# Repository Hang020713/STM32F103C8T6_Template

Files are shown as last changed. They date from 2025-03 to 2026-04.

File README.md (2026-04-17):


# About This Project

A custom STM32F103C8T6 PCB template designed for hand-soldering, prototyping, and embedded system development.
This board serves as a solid starting point for STM32-based projects, robotics systems, and embedded applications.

---

# 📟 Board Preview

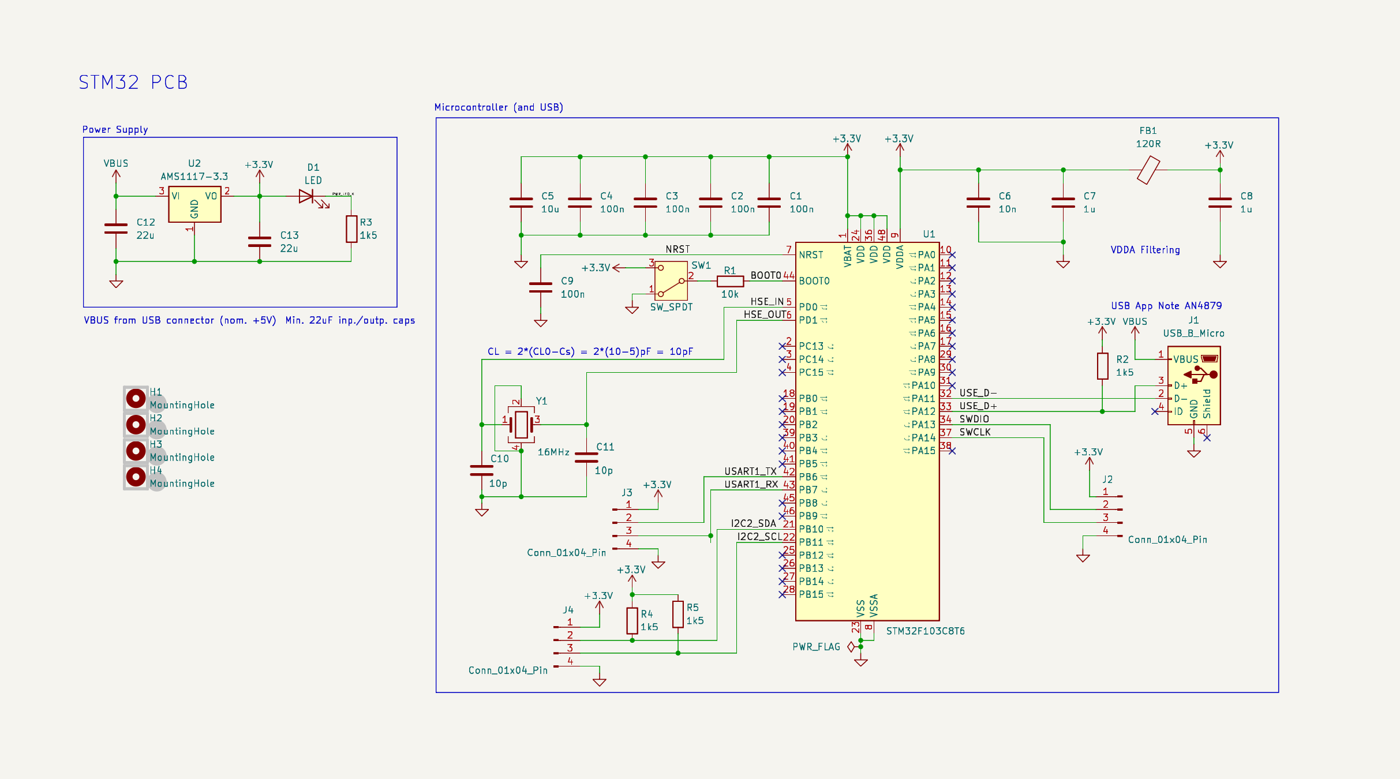
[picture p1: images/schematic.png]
schematic

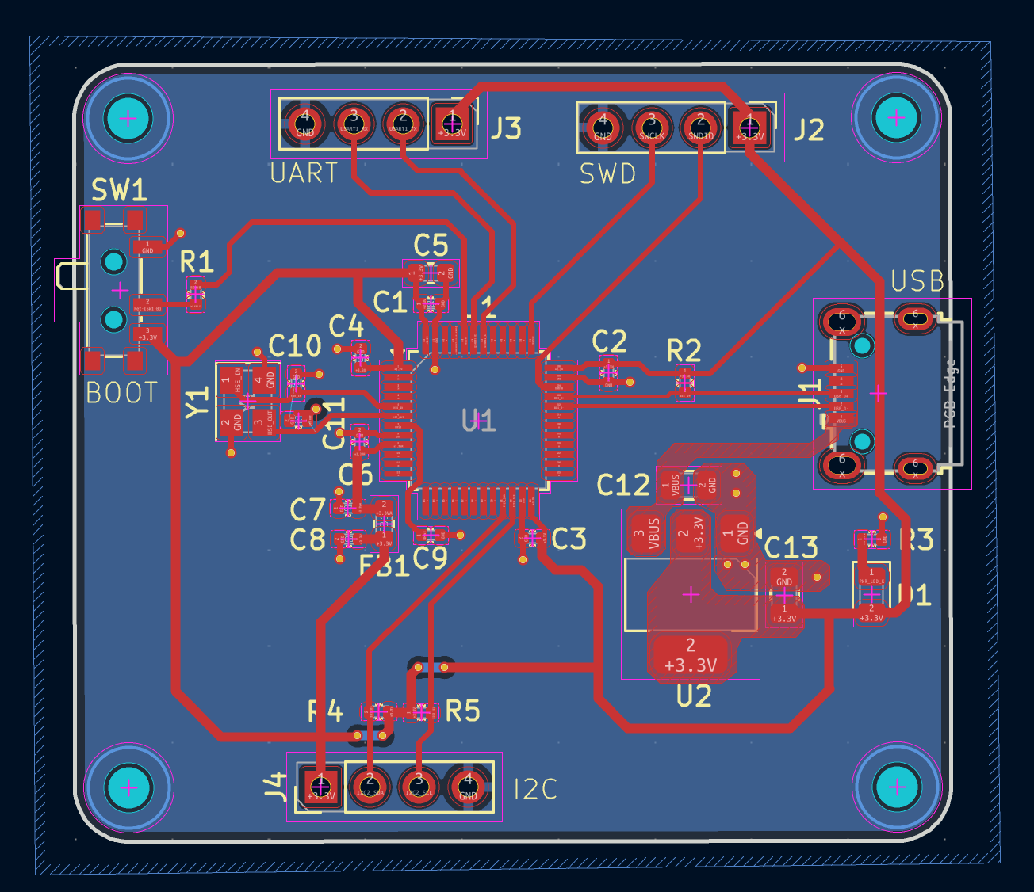
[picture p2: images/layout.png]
layout

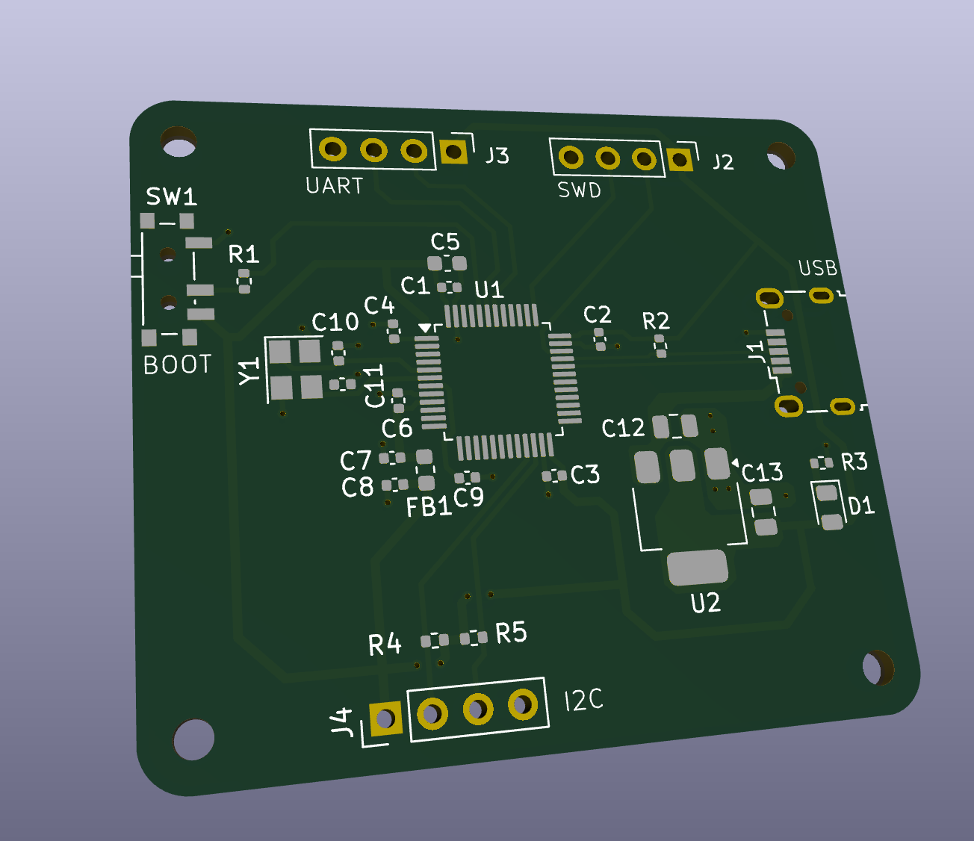
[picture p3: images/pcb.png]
[pcb]


---

# 📁 File Structure

<!-- TREEVIEW START -->
```bash
├── stm32f103c8t6.kicad_pcb   # PCB Layout
├── stm32f103c8t6.kicad_pro   # KiCad Project File
├── stm32f103c8t6.kicad_sch   # Schematic
└── README.md
```

## File Descriptions
* `kicad_pcb` - PCB Layout
* `kicad_sch` - Schematic
* `kicad_pro` - KiCad Project Configuration File
<!-- TREEVIEW END -->

---

# 🚀 Getting Started

Requirements
* KiCad 8 (recommended)

Open the `.kicad_pro` file using KiCad 8 to access the full project including schematic and PCB layout.

---

# 🔧 Board Feature

STM32 Board have below features
- [x] Hand-solder friendly footprint design
- [x] 5V Voltage Regulator
- [x] Micro USB Connector
- [x] 1 x UART Interface
- [x] 1 x I2C Interface
- [x] BOOT Button
- [x] SWD Debugging Interface
- [x] 16 MHz External Crystal Oscillator
- [ ] USB-C Connector

---

# 🧠 Usage

STM32 have a deep potential. You could modify this board to extend more pins you want. Example:

* Expose additional GPIO Pins
* Add SPI peripherals
* Integreate sensors (IMU, barometer, etc.)
* Add motor drivers

---

# License

MIT License

Feel free to use, modify, and distribute.

---

## 📫 Let's Connect

I'm always interested in collaborating on embedded systems projects, robotics competitions, or autonomous vehicle development!







---

<p align="right">(<a href="#readme-top">Back to Top</a>)</p>

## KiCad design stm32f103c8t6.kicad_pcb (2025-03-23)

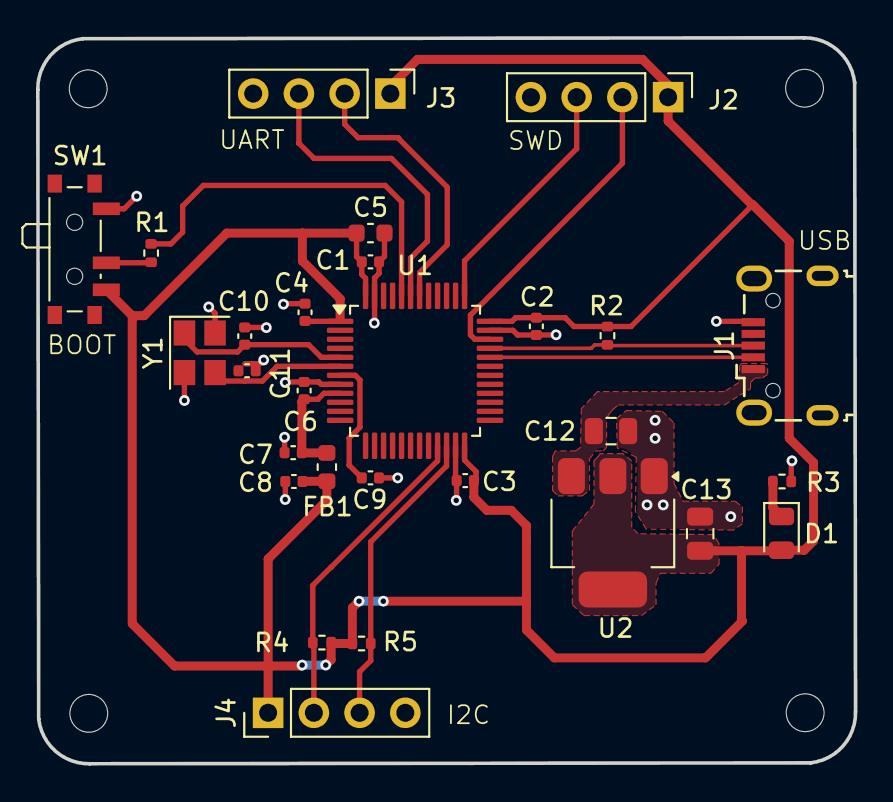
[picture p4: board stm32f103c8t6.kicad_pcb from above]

Board: 2 copper layers, 45.4 x 40.3 mm, 32 parts (0 on the bottom side), 18 nets.

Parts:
C1, C2, C3, C4, C9: 100n; C_0402_1005Metric
C5: 10u; C_0603_1608Metric
C6: 10n; C_0402_1005Metric
C7, C8: 1u; C_0402_1005Metric
C10, C11: 10p; C_0402_1005Metric
C12, C13: 22u; C_0805_2012Metric
D1: LED; LED_0805_2012Metric
FB1: 120R; L_0603_1608Metric
H1, H2, H3, H4: MountingHole; MountingHole_2.1mm
J1: USB_B_Micro; USB_Micro-B_Wuerth_629105150521
J2, J3, J4: Conn_01x04_Pin; PinHeader_1x04_P2.54mm_Vertical
R1: 10k; R_0402_1005Metric
R2, R3, R4, R5: 1k5; R_0402_1005Metric
SW1: SW_SPDT; SW_SPDT_PCM12
U1: STM32F103C8T6; LQFP-48_7x7mm_P0.5mm
U2: AMS1117-3.3; SOT-223-3_TabPin2
Y1: 16MHz; Crystal_SMD_3225-4Pin_3.2x2.5mm

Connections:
+3.3V: C1.1, C2.1, C3.1, C4.1, C5.1, C8.1, C13.1, D1.2 (A), FB1.1, J2.1, J3.1, J4.1, R2.1, R4.1, R5.1, SW1.3 (C), U1.1 (VBAT), U1.24 (VDD), U1.36 (VDD), U1.48 (VDD), U2.2 (VO)
+3.3VA: C6.1, C7.1, FB1.2, U1.9 (VDDA)
/BOOT0: R1.2, U1.44 (BOOT0)
/HSE_IN: C10.1, U1.5 (PD0), Y1.1
/HSE_OUT: C11.1, U1.6 (PD1), Y1.3
/I2C2_SCL: J4.3, R5.2, U1.22 (PB11)
/I2C2_SDA: J4.2, R4.2, U1.21 (PB10)
/NRST: C9.1, U1.7 (NRST)
/PWR_LED_K: D1.1 (K), R3.1
/SWCLK: J2.3, U1.37 (PA14)
/SWDIO: J2.2, U1.34 (PA13)
/USART1_RX: J3.3, U1.43 (PB7)
/USART1_TX: J3.2, U1.42 (PB6)
/USE_D+: J1.3 (D+), R2.2, U1.33 (PA12)
/USE_D-: J1.2 (D-), U1.32 (PA11)
GND: C1.2, C2.2, C3.2, C4.2, C5.2, C6.2, C7.2, C8.2, C9.2, C10.2, C11.2, C12.2, C13.2, J1.5 (GND), J2.4, J3.4, J4.4, R3.2, SW1.1 (A), U1.8 (VSSA), U1.23 (VSS), U1.35 (VSS), U1.47 (VSS), U2.1 (GND), Y1.2, Y1.4
unnamed: R1.1, SW1.2 (B)
VBUS: C12.1, J1.1 (VBUS), U2.3 (VI)

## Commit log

2025-03-23 Update V1
    [1.kicad_pcb, 1.kicad_sch]
2025-06-15 Add 2x2 keyboards
    [1-B_Cu.gbr, 1-B_Mask.gbr, 1-B_Paste.gbr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]
2026-04-12 chore: tidy repo format
    - Update git ignore
    - Remove backup files
    - Tidy Readme
    [1-B_Cu.gbr, 1-B_Mask.gbr, 1-B_Paste.gbr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]
2026-04-17 feat: update readme images
    Added board preview section
2026-04-17 chore: kicad_pro
